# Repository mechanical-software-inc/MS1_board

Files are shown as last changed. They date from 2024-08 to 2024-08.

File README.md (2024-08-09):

# Design files for MS1 board

## Features
* 6 rp2040 pico's using i2c<->i2c comms for i/o sharing
* 1 rp2040 pico dedicated to ethernet communication (broken on current board, fixing)
* 10x24V Discrete outputs (2 per pico, 5 picos)
* 20x24V Discrete inputs (4 per pico, 5 picos)
* 18x4-20mA inputs (3 per pico, 6 picos) - implemented with rp2040 i/o and external 16-bit i2c ADC - can use without external ADC if needed
* 5x4-20mA outputs (1 per pico, 5 picos)
* 256KB EEPROM with unique 32bit serial number for board ID
* RPi umbilical for pico programming, monitoring, i2c comms

## Images
### Current (block 3)
<p align="center">
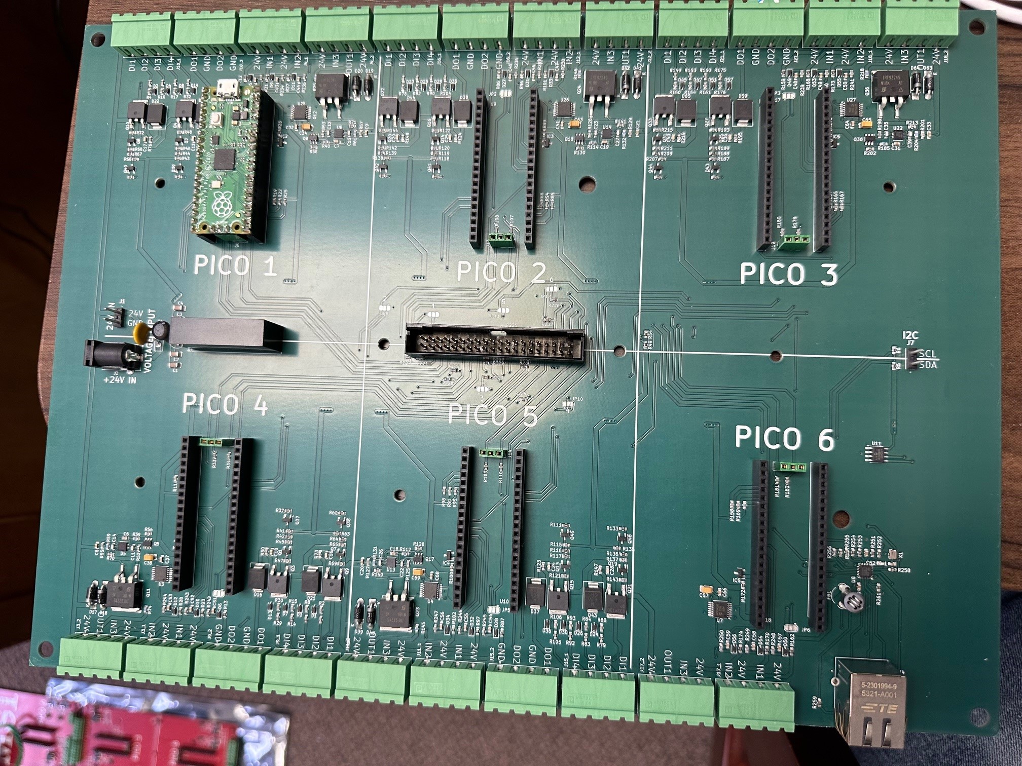
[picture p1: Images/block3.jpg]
block 3 image
  
</p>

### Past (blocks 1-3)
* Green is standard spec and cheaper for testing, will probably return to red at some point
* Old style terminal blocks were too small and hard to swap
* Non-resettable fuse was dumb
* Lots of issues with debug pin trace routing and sizing - believe these have been sorted
* Bigger power supply
* On-board ethernet (not working yet, stack is 90%, but pinout is messed up on current board)
* On-board eeprom is new - better than using pico flash chip for ID
* On-board ADC for 4-20mA inputs is new to block 3 - voltage inputs are fed to external ADC and pico inputs for comparison and use when external ADC chips are unobtainium
* Fixed many grounding and power connector issues
<p align="center">
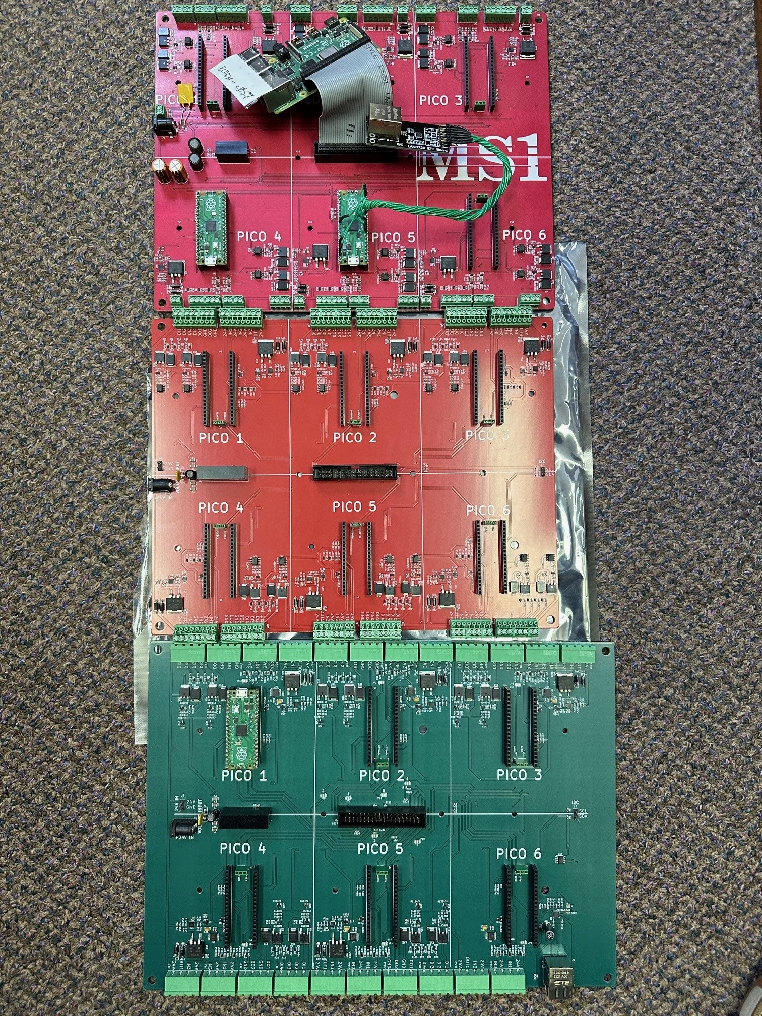
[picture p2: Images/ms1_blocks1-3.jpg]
blocks 1,2,3 image
  
</p>

### Software
* Tooling and ethernet stack with Ethernet/IP (industrial protocol) host and MQTT support, still working out bugs, contact for more info

### Limitations
* Board size is not currently a factor for us, we are typically building large control panels
* Will probably create a few different form factors in the future (1-4 picos is easy to see happening)
* i2c comms for inter-board messaging is probably not ideal, but works for us

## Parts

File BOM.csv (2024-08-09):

# | Reference | Qty | Value | Footprint | Mfg PN
1 | C1, C2, C3, C4 | 4 | 47uF | Capacitor_SMD:C_1206_3216Metric | C3216X5R1E476M160AC
2 | C5 | 1 | 22uF | Capacitor_SMD:C_0603_1608Metric | GRM188R61A226ME15D
3 | C6, C7, C18, C19, C31, C32, C37, C41, C42, C43, C44, C45, C46, C47, C48, C49, C50, C51, C52, C53, C54, C55, C56, C57, C58, C59, C60, C64, C66, C68 | 30 | 100nF | Capacitor_SMD:C_0603_1608Metric | C1608X7R1H104K080AA
4 | C8, C9, C20, C21, C33, C61 | 6 | 1uF | Capacitor_SMD:C_0603_1608Metric | CL10A105KL8NNNC
5 | C10, C13, C16, C17, C24, C25, C28, C29, C36, C40 | 10 | 0.01uF | Capacitor_SMD:C_0603_1608Metric | C0603C103K5RAC7867
6 | C11, C12, C14, C15, C22, C23, C26, C27, C35, C39 | 10 | 220pF | Capacitor_SMD:C_0603_1608Metric | 06035A221JAT2A
7 | C30 | 1 | .022uF | Capacitor_SMD:C_0603_1608Metric | CGA3E2X7R1H223K080AA
10 | C62 | 1 | 470pF | Capacitor_SMD:C_0603_1608Metric | C0603C471J5GAC7867
11 | C34, C38, C63, C65, C67, C69 | 4 | T491A106K010AT | Capacitor_SMD:C_1206_3216Metric | T491A106K010AT
12 | D1, D2, D3, D4, D5, D6, D7, D8, D9, D10, D11, D12, D13, D14, D23, D24, D25, D26, D27, D28, D29, D30, D31, D32, D33, D34, D35, D36, D45, D47, D49, D50, D51, D53, D54, D55, D56, D57 | 38 | 3.9V | Diode_SMD:D_SOD-323 | MM3Z3V9ST1G
13 | D15, D16, D21, D22, D37, D38, D43, D44, D59, D65 | 10 | 5A | Diode_SMD:D_SMC | VS-5ECH06-M3/9AT
14 | D17, D18, D19, D20, D39, D40, D41, D42, D63, D64 | 10 | D | Diode_THT:D_DO-41_SOD81_P7.62mm_Horizontal | 1N4007-T
15 | F1 | 1 | 3A | Fuse:Fuse_Bourns_MF-RHT200 | MF-RHT200/32-2
16 | FB1 | 1 | 28C0236-0JW-10 | Ferrite_THT:LairdTech_28C0236-0JW-10 | 28C0236-0JW-10
19 | IC1, IC2, IC3, IC4, IC5, IC6 | 6 | LM4040C30FTA | Package_TO_SOT_SMD:SOT-23 | LM4040C30FTA
20 | J1 | 1 | 24V IN | NAGG:1945096 | 1945096
21 | J2 | 1 | +24V IN | Connector_BarrelJack:BarrelJack_CUI_PJ-102AH_Horizontal | PJ-102AH
22 | J3 | 1 | RJ45_RB1-125B8G1A | Connector_RJ:RJ45_UDE_RB1-125B8G1A | 5-2301994-9
23 | J3_1, J3_2, J4_1, J4_2, J9_1, J9_2, J10_1, J10_2, J11_1, J11_2, J12_1, J12_2, J15_1, J15_2, J16_1, J16_2, J17_1, J17_2, J18_1, J18_2, J21_1, J21_2 | 22 | Screw_Terminal_01x04 | Connector_Phoenix_MSTB:PhoenixContact_MSTBA_2,5_4-G-5,08_1x04_P5.08mm_Horizontal | 1757268
24 | J5, J6, J13, J14, J19, J20 | 6 | Conn_01x03 | Connector_PinSocket_2.54mm:PinSocket_1x03_P2.54mm_Vertical | 215299-3
25 | J7 | 1 | Conn_01x02 | NAGG:1945096 | 1945096
26 | J8 | 1 | Conn_02x20_Odd_Even | Connector_PinHeader_2.54mm:PinHeader_2x20_P2.54mm_Vertical | 6-103169-8
28 | L1 | 1 | 22uH | Inductor_THT:L_Radial_D7.0mm_P3.00mm | RLB0712-220KL
29 | PS1 | 1 | K7805-3AR3 | NAGG:CONV_K7805-3AR3 | K7805-3AR3
30 | Q1, Q2, Q7, Q8, Q13, Q14, Q19, Q20, Q25, Q31 | 10 | DMN10H220L | Package_TO_SOT_SMD:SOT-23 | DMN10H220L-7
31 | Q3, Q4, Q9, Q10, Q15, Q16, Q21, Q22, Q27, Q33 | 10 | RD3P130S | Package_TO_SOT_SMD:TO-252-2 | RD3P130SPFRATL
32 | Q5, Q6, Q17, Q18, Q30 | 5 | NDC7002N | Package_TO_SOT_SMD:SOT-23-6 | NDC7002N
33 | Q11, Q12, Q23, Q24, Q36 | 5 | IRF9Z24S | Package_TO_SOT_SMD:TO-263-2 | IRF9Z24SPBF
34 | Q37, Q38, Q39, Q40, Q41, Q42, Q43, Q44, Q45, Q46 | 10 | MMBT3904 | Package_TO_SOT_SMD:SOT-23 | MMBT3904
35 | R1, R3, R7, R9, R14, R16, R29, R31, R77, R79, R81, R83, R89, R92, R103, R105, R149, R153, R160, R175 | 20 | 68K | Resistor_SMD:R_0603_1608Metric | RC0603FR-0768KL
36 | R2, R4, R8, R10, R11, R15, R17, R18, R19, R20, R22, R25, R30, R32, R33, R34, R35, R36, R47, R48, R55, R57, R69, R72, R78, R80, R82, R84, R85, R88, R90, R91, R93, R94, R95, R98, R104, R106, R107, R108, R109, R110, R121, R122, R127, R129, R143, R144, R150, R154, R157, R158, R161, R165, R166, R167, R169, R176, R179, R180, R181, R182, R193, R201, R215, R221, R222, R223, R224, R225, R226, R227, R228, R229, R230, R231, R232, R233, R234, R235, R236, R237, R238, R239, R240, R241, R242, R243, R244, R245, R246, R247, R248, R249, R250 | 95 | 10K | Resistor_SMD:R_0603_1608Metric | ERJ-3GEYJ103V
37 | R5, R6, R49, R54 | 4 | 5.1K | Resistor_SMD:R_0603_1608Metric | ERJ-3EKF5101V
38 | R12, R13, R21, R23, R27, R28, R42, R44, R64, R67, R86, R87, R96, R97, R101, R102, R116, R119, R136, R139, R159, R162, R168, R170, R173, R174, R188, R208 | 28 | 150 | Resistor_SMD:R_0603_1608Metric | CR0603-JW-151ELF
39 | R24, R26, R37, R38, R60, R62, R99, R100, R111, R113, R133, R134, R171, R172, R183, R205 | 16 | 1K | Resistor_SMD:R_0603_1608Metric | CR0603-FX-1001ELF
40 | R39, R40, R112, R114, R185 | 5 | 16K | Resistor_SMD:R_0603_1608Metric | RK73H1JTTD1800F
41 | R41, R43, R63, R66, R115, R118, R135, R138, R187, R207 | 10 | 3.3K | Resistor_SMD:R_0603_1608Metric | RC0603JR-103K3L
42 | R45, R46, R65, R68, R117, R120, R137, R142, R189, R211 | 10 | 100K | Resistor_SMD:R_0603_1608Metric | RC0603JR-07100KL
43 | R50, R51, R52, R53, R70, R71, R73, R76, R123, R124, R125, R126, R140, R141, R147, R148, R195, R198, R213, R219 | 20 | 100 | Resistor_SMD:R_0603_1608Metric | RC0603FR-07100RL
44 | R56, R58, R128, R130, R202 | 5 | 6.2K | Resistor_SMD:R_0603_1608Metric | CRCW06036K20FKEAC
45 | R59, R61, R131, R132, R204 | 5 | 249 | Resistor_SMD:R_0603_1608Metric | RK73H1JTTD2490F
46 | R74, R75, R145, R146, R218 | 5 | 22.1 | Resistor_SMD:R_0603_1608Metric | RK73H1JTTD22R1F
47 | R251, R252, R253, R254 | 4 | 10 | Resistor_SMD:R_0603_1608Metric | RMCF0603FT10R0
48 | R255 | 1 | 1.5k | Resistor_SMD:R_0603_1608Metric | RC0603JR-071K5L
49 | R256, R257, R258 | 3 | 33 | Resistor_SMD:R_0603_1608Metric | RC0603FR-0733R2L
50 | R259, R260 | 2 | 332 | Resistor_SMD:R_0603_1608Metric | RMCF0603FT332R
51 | R261 | 1 | 12.1k | Resistor_SMD:R_0603_1608Metric | RMCF0603FT12K1
52 | U1, U2, U9, U10, U17, U18 | 6 | PICO_RP2040 | NAGG:Rasp_Pi_PICO | M20-7822046
53 | U3, U4, U7, U25, U26, U27 | 6 | MCP3428x-xST | Package_SO:TSSOP-14_4.4x5mm_P0.65mm | MCP3428-E/ST
54 | U5, U6, U13, U14, U22 | 5 | Opamp_Dual_Generic | Package_DFN_QFN:DFN-8-1EP_3x3mm_P0.5mm_EP1.65x2.38mm | LT1490ACDD#TRPBF
55 | U8 | 1 | LAN8720A | Package_DFN_QFN:VQFN-24-1EP_4x4mm_P0.5mm_EP2.5x2.5mm_ThermalVias | LAN8720AI-CP-TR
56 | U11 | 1 | 24AA256UIDT-I/SN | Package_SO:SOIC-8_3.9x4.9mm_P1.27mm | 24AA256UIDT-I/SN
57 | X1 | 1 | ECS-2033-500-BN | Oscillator:Oscillator_SMD_ECS_2520MV-xxx-xx-4Pin_2.5x2.0mm | ECS-2033-500-BN
